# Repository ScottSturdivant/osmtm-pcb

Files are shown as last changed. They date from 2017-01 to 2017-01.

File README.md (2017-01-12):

# osmtm-pcb
Overnight Sensations MTM Printed Circuit Board Project

The [OS MTM](https://sites.google.com/site/undefinition/overnightsensationmtm) is a nice little speaker setup designed by Paul Carmody.
There are DIY kits available at [DIY Sound Group](http://www.diysoundgroup.com/speaker-kits/overnight-sensation/osmtm-flat-pack.html).  If
you're nervous about assembling the crossover, you may simply take these Gerber files and get them produced from any PCB manufacturer.
The cost is ~$20USD for 5 boards from the cheaper Chinese shops while some (PCBWay) offer $1/board for 10 boards if under 100mm x 100mm.

## Why
While waiting for the OS MTM kits to come back in stock, and hating the idea of an MDF or pegboard based crossover, I figured I'd dust off my EE skills
and take a stab at laying out a PCB, using the [KiCad](http://kicad-pcb.org) program.  This is purely overkill, you do not *need* a PCB, but it sure is nice.  And pretty.  Inside your
speaker cabinet.

## Schematic
To start, I took Paul's original schematic:

OS MTM

And redrew it in KiCad:

OS MTM KiCad

## Footprints
The Bill of Materials was cross referenced against the part spec sheets to draw the footprints for the various components.  The inductors
however were slightly made up as I didn't have the inner diameter of the coil.

Mounting holes for standard 3mm pan head wood screws are included, but standoffs are required.

There are holes for zip ties with a max width of 5mm used to hold the inductors in place.

The resulting PCB winds up looking like this:

OS MTM PCB Layout

## PCB Board

Using the excellent 3D models included with KiCad, here's what the board will mostly look like once built and assembled:

Front:

OS MTM PCB Front

Back:

OS MTM PCB Rear

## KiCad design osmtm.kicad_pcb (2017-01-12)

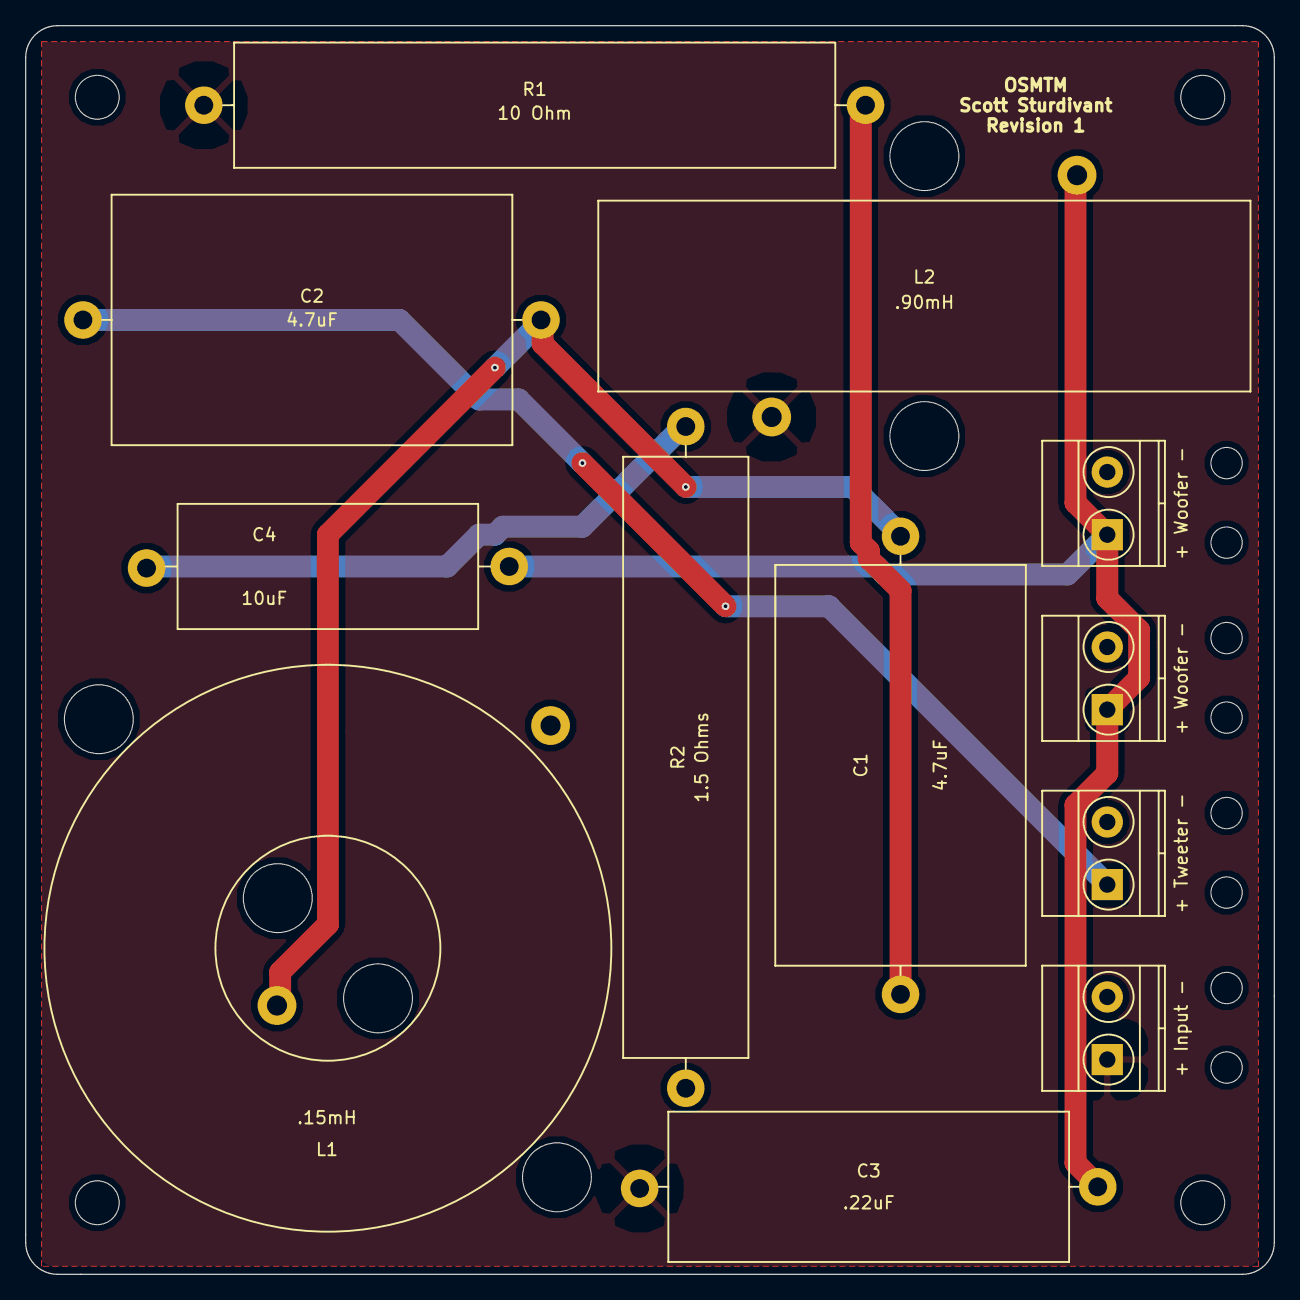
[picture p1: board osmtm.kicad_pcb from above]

Board: 2 copper layers, 99.7 x 99.7 mm, 12 parts (0 on the bottom side), 7 nets.

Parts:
+ Input -: Screw_Terminal_1x02; TerminalBlock_Pheonix_MKDS1.5-2pol
+ Tweeter -: Speaker; TerminalBlock_Pheonix_MKDS1.5-2pol
+ Woofer -: Speaker; TerminalBlock_Pheonix_MKDS1.5-2pol
+ Woofer -#2: Speaker; TerminalBlock_Pheonix_MKDS1.5-2pol
C1, C2: 4.7uF; Dayton4.7uF
C3: .22uF; Dayton0.22uF
C4: 10uF; Dayton10uFNPE
L1: .15mH; JantzenAudio0.15mhInductor
L2: .90mH; JantzenAudio90mHInductor
R1: 10 Ohm; Dayton10Ohm
R2: 1.5 Ohms; Dayton1.5Ohm

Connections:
BLACK: + Input -.2, + Tweeter -.2, + Woofer -.2, + Woofer -#2.2, L1.2, R2.2
unnamed: C1.1, C2.2, L1.1
unnamed: C1.2, R1.1
unnamed: + Tweeter -.1, C2.1
unnamed: + Woofer -.1, + Woofer -#2.1, C3.1, C4.1, L2.1
unnamed: C4.2, R2.1
RED: + Input -.1, C3.2, L2.2, R1.2

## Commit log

2017-01-10 Initial commit of the OSMTM PCB.
    [osmtm.kicad_pcb, osmtm.sch]
2017-01-11 Use screw terminals, increase trace width.
    The trace width was incorrectly using the results for external lines
    when it should have been using internal. As a result of this (and the
    screw terminal change), the inductor footprints were also modified and
    the amount of zip ties used reduced.
    [osmtm.kicad_pcb, osmtm.sch]
2017-01-11 Update schematic pic in README.
2017-01-12 Adapt board to 100mm x 100mm sizing.
    [osmtm.kicad_pcb]
